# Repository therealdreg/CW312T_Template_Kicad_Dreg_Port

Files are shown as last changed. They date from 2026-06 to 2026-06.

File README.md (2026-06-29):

# CW312T_Template_Kicad_Dreg_Port

chipwhisper CW312T template for KiCad with Dreg port (and easyeda file to import)

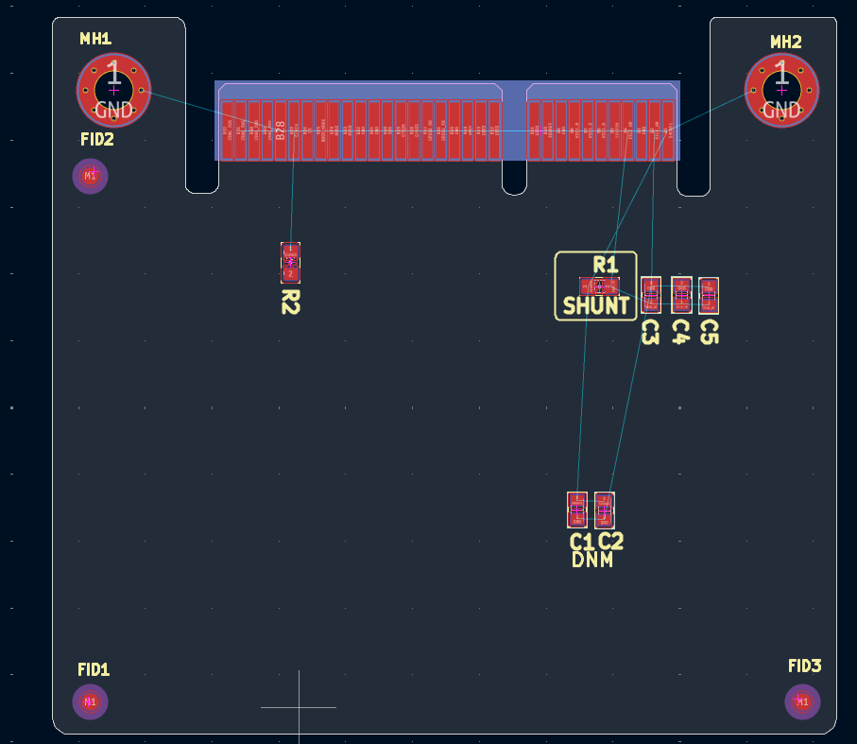
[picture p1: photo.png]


------

## PCB specs

- Thickness: 1.6 mm (0.062"). Required by the CW312 card-edge connector (Samtec MECF), and it's the default thickness anyway, so no extra cost.
- Edge fingers: ENIG + "gold fingers" (solder mask removed over the pads) is enough for a target plugged in/out a few dozen times. Note JLCPCB only does "gold fingers" with ENIG selected, this is NOT real electroplated hard gold. Use real hard gold (e.g. PCBWay) only if you need hundreds/thousands of insertions.
- Bevel/chamfer (30°): JLCPCB won't bevel boards smaller than 50 x 50 mm, and can't bevel V-cut panelized fingers. Fine to skip on small targets, the MECF socket has its own lead-in.

-----

# kicad project 

[CW312T_Template_Kicad_Dreg_Port.zip](CW312T_Template_Kicad_Dreg_Port.zip)

------

# easyeda pro file to import

[ProPrj_CW312T_Template_Kicad_Dreg_Port_2026-06-29.epro2](ProPrj_CW312T_Template_Kicad_Dreg_Port_2026-06-29.epro2)

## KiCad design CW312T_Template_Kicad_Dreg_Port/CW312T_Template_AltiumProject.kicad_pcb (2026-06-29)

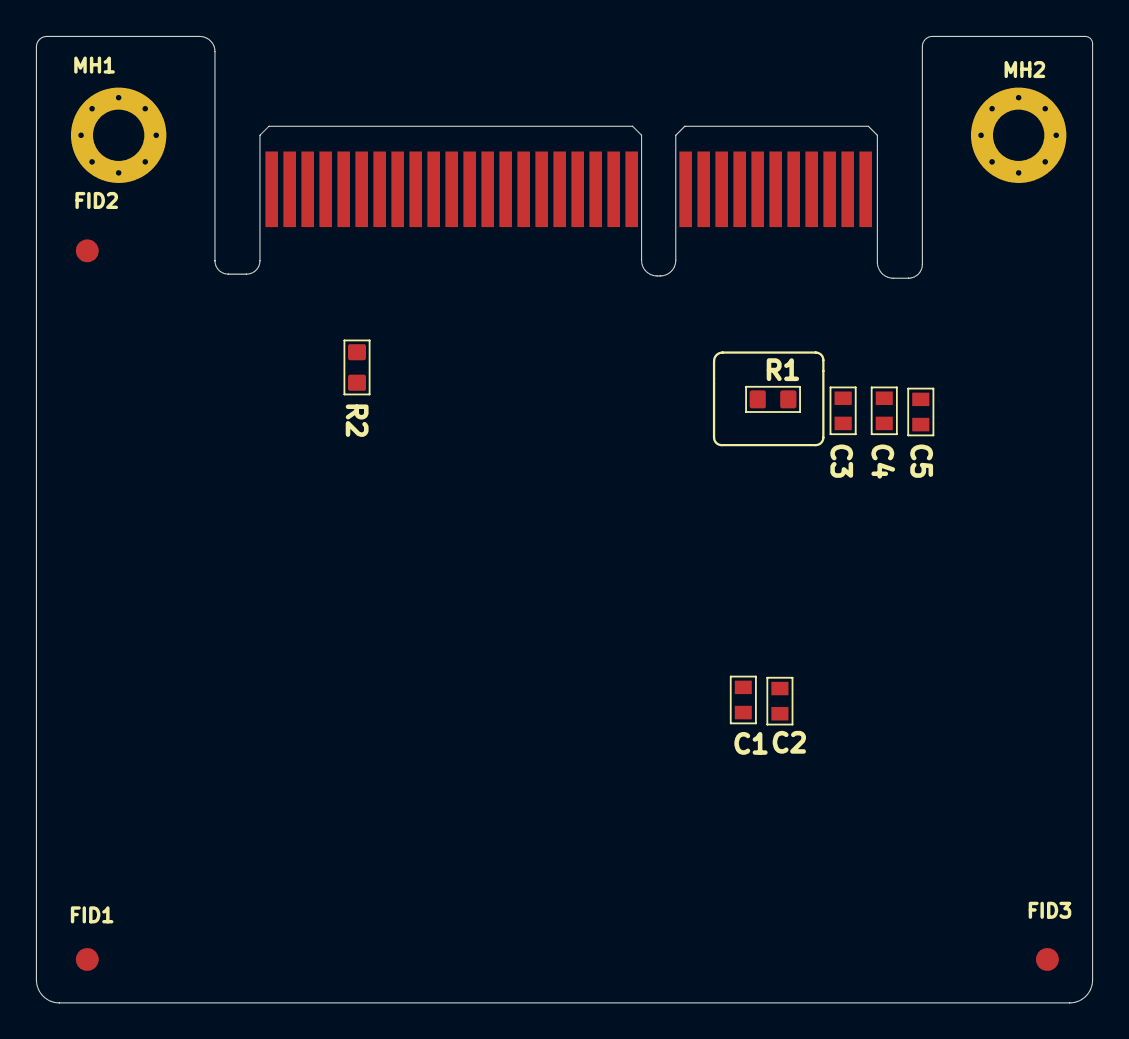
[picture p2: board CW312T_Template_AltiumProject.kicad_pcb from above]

Board: 2 copper layers, 58.7 x 53.7 mm, 13 parts (0 on the bottom side), 6 nets, no tracks yet.

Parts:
C1, C2: DNM; CAPC0603_M
C3, C4: 100n; CAPC0603_M
C5: 2u2; CAPC0603_M
FID1, FID2, FID3: FIDU-ROUND-1.0MM; FIDU-ROUND-1.0mm
MH1, MH2: 4-40 MH, Tight Fit; MOUNT_#4_TIGHT
P1: PCIeX4-GF-2D-1000-1K-O64
R1, R2: 10R; RESC1608X55N

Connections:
CLKIN: P1.B27, R2.1
FILT_HP: C3.1, C4.1, C5.1, P1.A3, P1.B2, P1.B4, R1.2
GND: C1.2, C2.2, C3.2, C4.2, C5.2, MH1.1, MH2.1, P1.A1, P1.A2, P1.A8, P1.A20, P1.A27, P1.A28, P1.B3, P1.B9, P1.B15, P1.B21, P1.B22
IOVREF: P1.A5, P1.A26, P1.B10
SHUNTL: C1.1, C2.1, P1.B1, R1.1
nRST: P1.A31, P1.B14

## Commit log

2026-06-29 first version
    [CW312T_Template_AltiumProject.PrjPcb, CW312T_Template_AltiumProject.kicad_pcb, CW312T_Template_AltiumProject.kicad_sch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]
2026-06-29 Add PCB specs section to README
    Added PCB specifications to the README.
2026-06-29 Revise PCB specs in README.md
    Updated PCB specifications for connector requirements and edge fingers.

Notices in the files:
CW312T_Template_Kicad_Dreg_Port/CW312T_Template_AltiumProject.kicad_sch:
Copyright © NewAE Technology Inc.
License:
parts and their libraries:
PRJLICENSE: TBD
